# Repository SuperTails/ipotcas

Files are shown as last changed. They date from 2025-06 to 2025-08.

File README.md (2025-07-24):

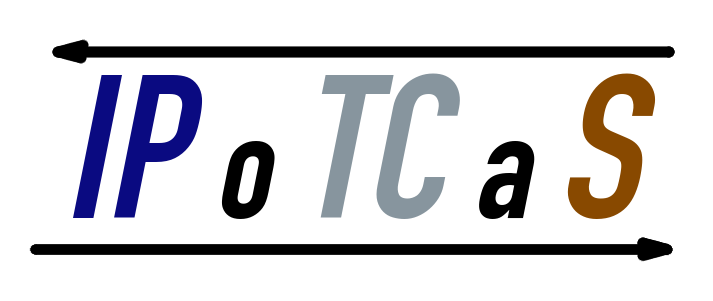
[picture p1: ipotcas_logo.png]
IPoTCaS logo


**IP over Tin Can and String** (IPoTCaS, pronounced "eye-poh-tee-kass"),
also known as EtherKnit or "what is this annoying buzzing noise",
is a revolutionary new way to connect to the internet over a fiber connection.

Using only two pieces of string and lots of annoying sounds,
IPoTCaS can create a **6.9 kbps** connection capable of browsing the web,
downloading files, and giving you a newfound distaste for web bloat.

# Physical Setup

The linear rails are sourced from two listings on Amazon,
but I'd highly recommend just using the first one because the wider rails are much worse
(though the CAD will require some modification):
- [Small rails](https://www.amazon.com/dp/B0D54LDBHN?ref=ppx_yo2ov_dt_b_fed_asin_title)
- [Large rails](https://www.amazon.com/dp/B088B6XN2J?ref=ppx_yo2ov_dt_b_fed_asin_title&th=1)

Any generic Kevlar kite string will probably work,
but I used specifically
[this amazon listing](https://www.amazon.com/dp/B088PT4KKG?ref=ppx_yo2ov_dt_b_fed_asin_title&th=1)
from `emma kites`.

The mount CAD is available on
[Onshape](https://cad.onshape.com/documents/322e68c2d75961563174bd8a/w/bb42fd02dcb60f17fdcb0973/e/e357883cf5ed7cb39072be44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).
I have not tested with materials other than PLA.
The model is designed to work with metric heat-set inserts to hold down the rails.

# Modulation

IPoTCaS uses 32-QAM and 12-carrier OFDM between 7 and 14 kHz.

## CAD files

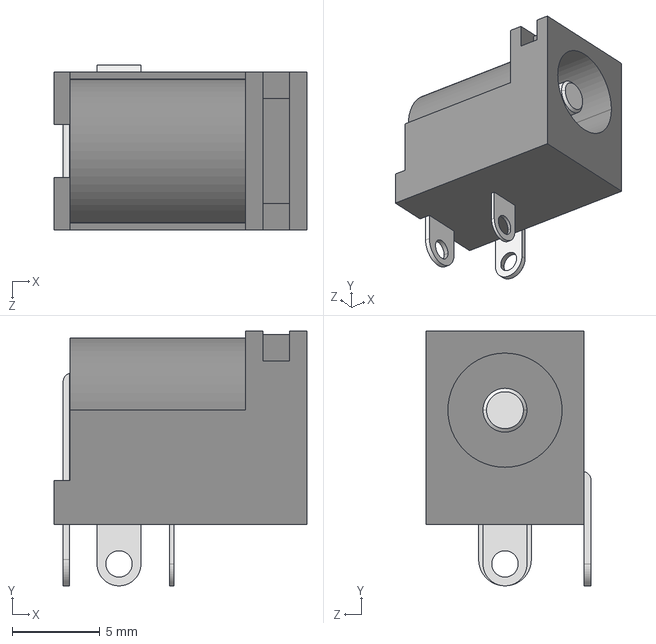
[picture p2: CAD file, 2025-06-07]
pcb/ipotcas/Custom/PJ-002B/PJ-002B.step
14.4 x 14.5 x 9.40 mm

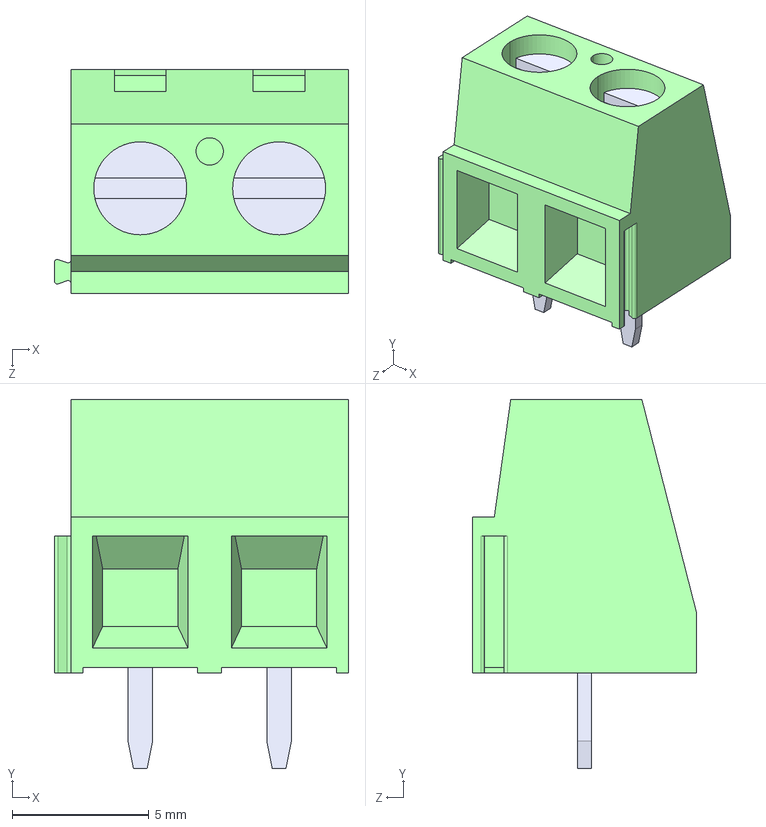
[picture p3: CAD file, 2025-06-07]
pcb/ipotcas/Custom/282837_2/282837-2.step
10.8 x 13.5 x 8.20 mm

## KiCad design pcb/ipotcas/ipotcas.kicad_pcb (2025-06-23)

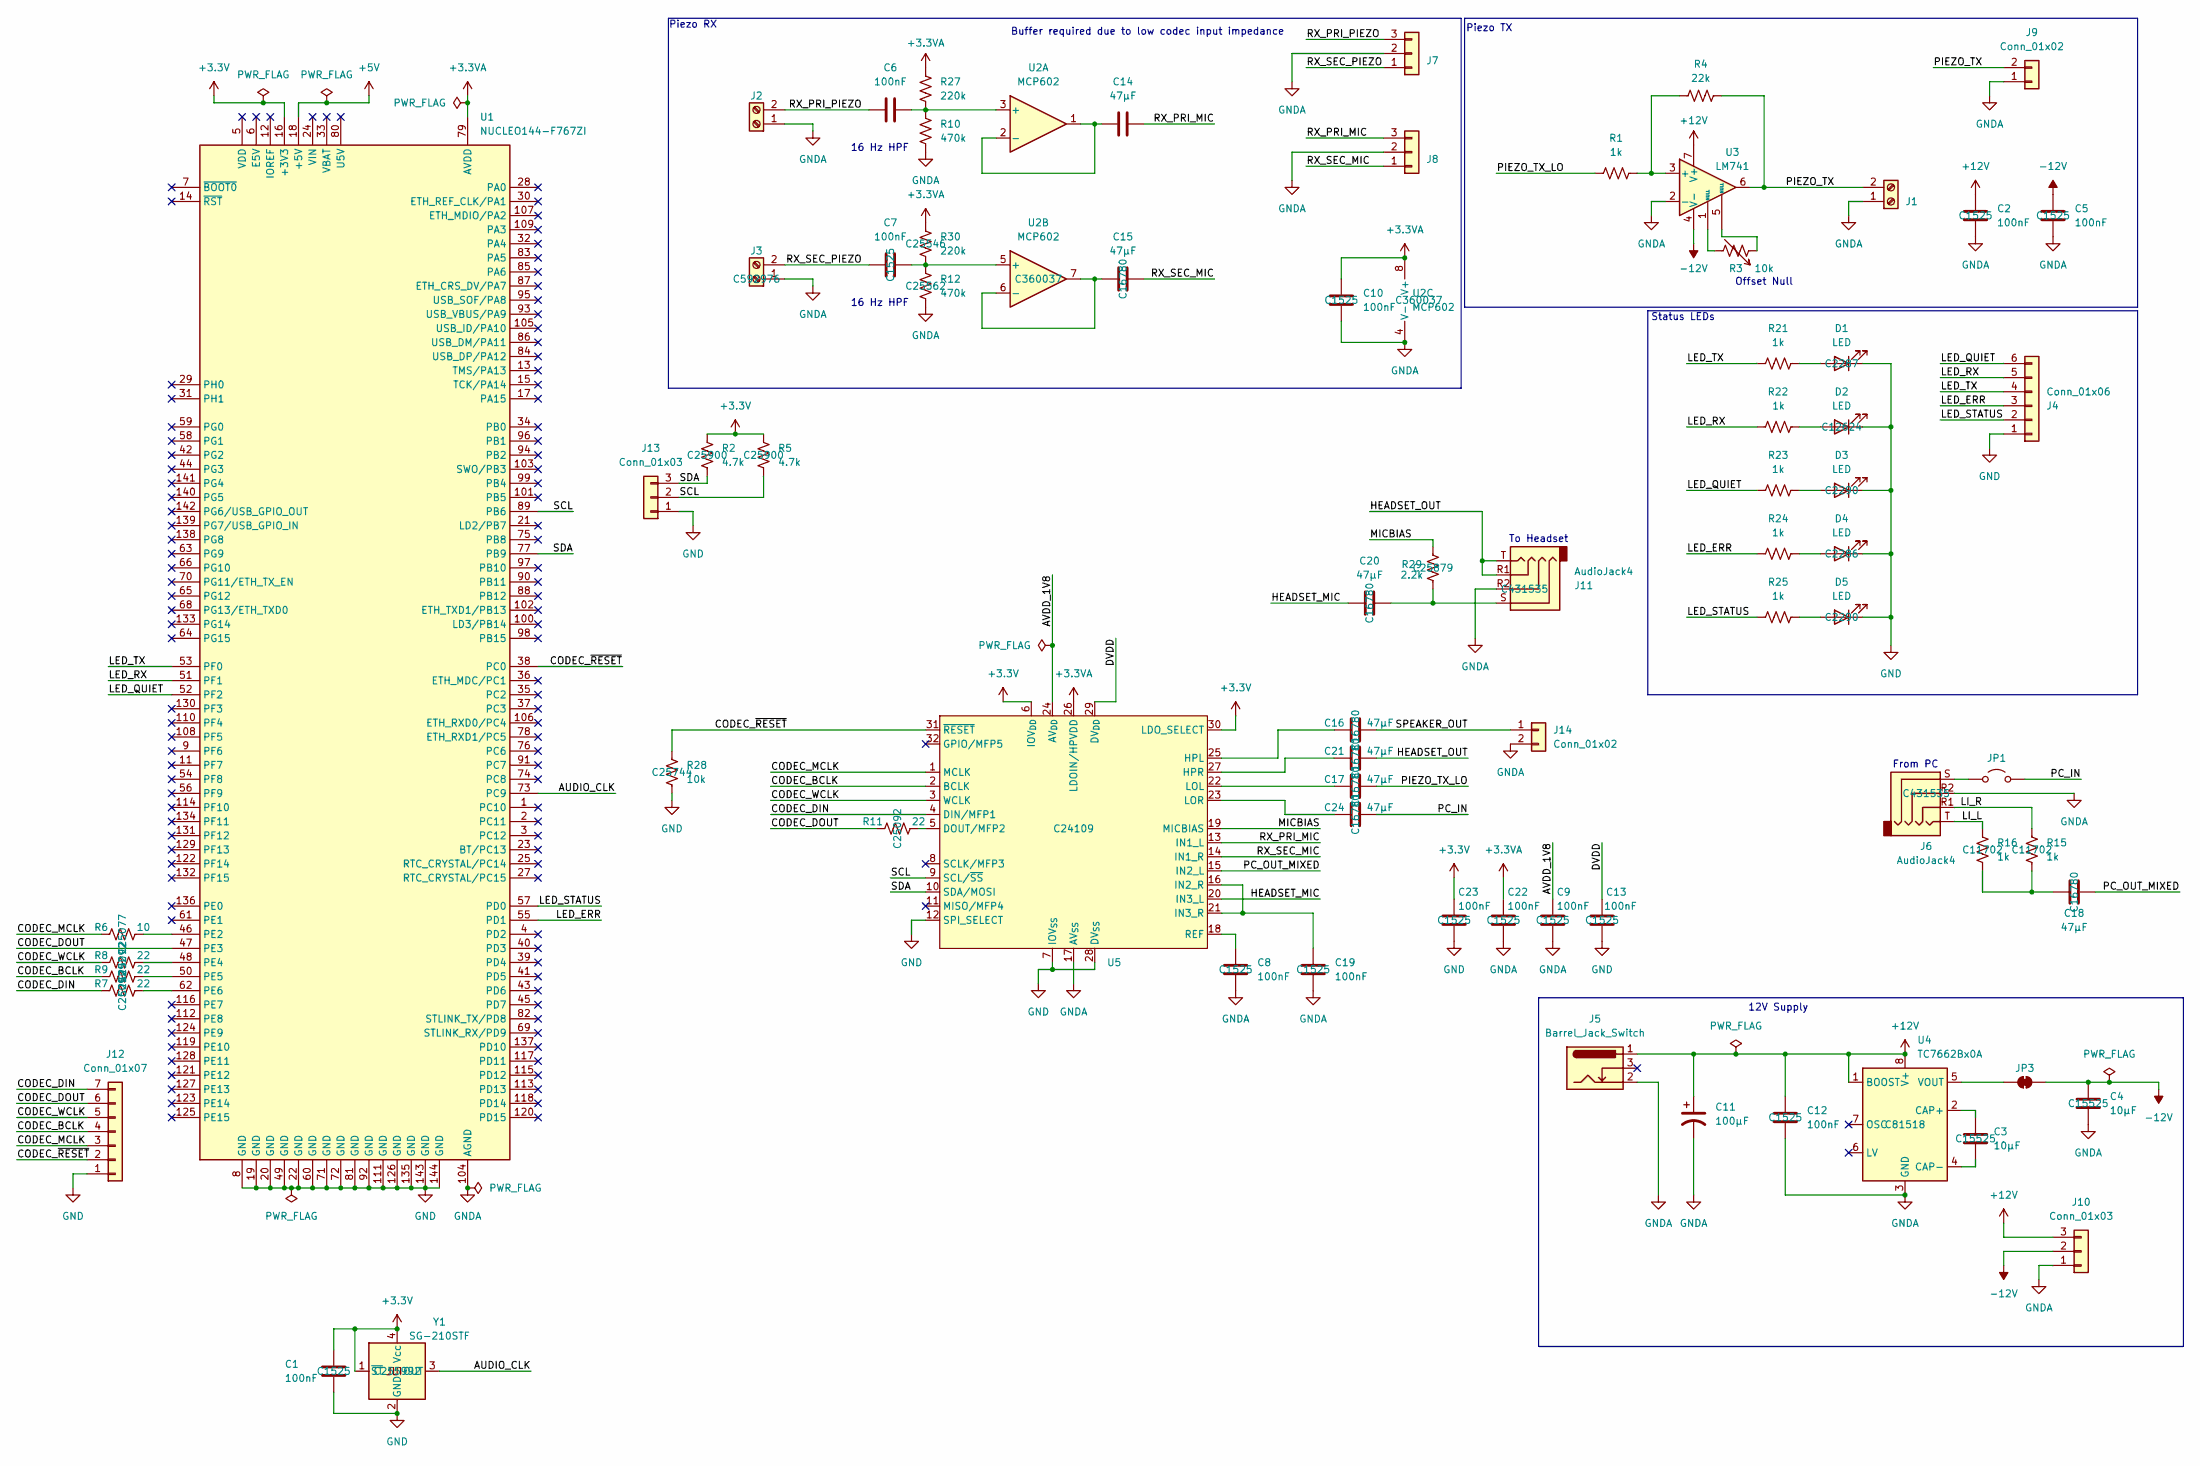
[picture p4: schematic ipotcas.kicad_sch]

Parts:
C1, C2, C5, C8, C9, C10, C12, C13, C19, C22, C23: 100nF; C_0402_1005Metric; JLC P/N C1525
C3, C4: 10µF; C_0402_1005Metric; JLC P/N C15525
C6, C7: 100nF; C_0402_1005Metric_Pad0.74x0.62mm_HandSolder; JLC P/N C1525
C11: 100µF; CP_Radial_D5.0mm_P2.50mm
C14, C15, C16, C17, C18, C20, C24: 47µF; C_0805_2012Metric; JLC P/N C16780
C21: 47µF; C_0603_1608Metric_Pad1.08x0.95mm_HandSolder; JLC P/N C16780
D1: LED; LED_0805_2012Metric_Pad1.15x1.40mm_HandSolder; JLC P/N C2287
D2: LED; LED_0805_2012Metric_Pad1.15x1.40mm_HandSolder; JLC P/N C12624
D3, D5: LED; LED_0805_2012Metric_Pad1.15x1.40mm_HandSolder; JLC P/N C2290
D4: LED; LED_0805_2012Metric_Pad1.15x1.40mm_HandSolder; JLC P/N C2286
J1, J2, J3: Screw_Terminal_01x02; TE_282837-2; JLC P/N C592976
J4: Conn_01x06; PinHeader_1x06_P2.54mm_Vertical
J5: Barrel_Jack_Switch; CUI_PJ-002B
J6, J11: AudioJack4; Jack_3.5mm_PJ320D_Horizontal; JLC P/N C431535
J7, J8, J10, J13: Conn_01x03; PinHeader_1x03_P2.54mm_Vertical
J9: Conn_01x02; PinHeader_1x02_P2.54mm_Vertical
J12: Conn_01x07; PinHeader_1x07_P2.54mm_Vertical
J14: Conn_01x02; PinSocket_1x02_P2.54mm_Vertical
JP1: Jumper_2_Open; PinHeader_1x02_P2.54mm_Vertical
JP3: SolderJumper_2_Bridged; SolderJumper-2_P1.3mm_Bridged_RoundedPad1.0x1.5mm
R1: 1k; R_0402_1005Metric_Pad0.72x0.64mm_HandSolder; JLC P/N C11702
R2, R5: 4.7k; R_0402_1005Metric; JLC P/N C25900
R3: 10k; Potentiometer_Bourns_3296W_Vertical; JLC P/N C118954
R4: 22k; R_0402_1005Metric_Pad0.72x0.64mm_HandSolder; JLC P/N C25768
R6: 10; R_0402_1005Metric; JLC P/N C25077
R7, R8, R9, R11: 22; R_0402_1005Metric; JLC P/N C25092
R10, R12: 470k; R_0402_1005Metric_Pad0.72x0.64mm_HandSolder; JLC P/N C25562
R15, R16: 1k; R_0402_1005Metric; JLC P/N C11702
R21, R22, R23, R24, R25: 1k; R_0805_2012Metric_Pad1.20x1.40mm_HandSolder
R27, R30: 220k; R_0402_1005Metric_Pad0.72x0.64mm_HandSolder; JLC P/N C25546
R28: 10k; R_0402_1005Metric; JLC P/N C25744
R29: 2.2k; R_0402_1005Metric; JLC P/N C25879
U1: NUCLEO144-F767ZI; ST_Morpho_Connector_144_STLink
U2: MCP602; SOIC-8_3.9x4.9mm_P1.27mm; JLC P/N C360037
U3: LM741; SOP-8_3.9x4.9mm_P1.27mm; JLC P/N C5145278
U4: TC7662Bx0A; SOIC-8_3.9x4.9mm_P1.27mm; JLC P/N C81518
U5: QFN-32-1EP_5x5mm_P0.5mm_EP3.45x3.45mm_ThermalVias; JLC P/N C24109
Y1: SG-210STF; Oscillator_SMD_SeikoEpson_SG210-4Pin_2.5x2.0mm; JLC P/N C255992

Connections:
+3.3V: C1.1, C23.1, R2.1, R5.1, U1.16 (+3V3), U5.6 (IOV_{DD}), U5.30 (LDO_SELECT), Y1.1 (~ST), Y1.4 (Vcc)
+3.3VA: C10.1, C22.1, R27.1, R30.1, U1.79 (AVDD), U2.8 (V+), U5.26 (LDOIN/HPVDD)
+5V: U1.18 (+5V)
+12V: C2.1, C11.1, C12.1, J5.1, J10.3, U3.7 (V+), U4.1 (BOOST), U4.8 (V+)
-12V: C4.1, C5.1, J10.2, JP3.2 (B), U3.4 (V-)
/AUDIO_CLK: U1.73 (PC9), Y1.3 (OUT)
/AVDD_1V8: C9.1, U5.24 (AV_{DD})
/CODEC_BCLK: J12.4, R9.1, U5.2 (BCLK)
/CODEC_DIN: J12.7, R7.1, U5.4 (DIN/MFP1)
/CODEC_DOUT: J12.6, R11.1, U1.47 (PE3)
/CODEC_MCLK: J12.3, R6.1, U5.1 (MCLK)
/CODEC_WCLK: J12.5, R8.1, U5.3 (WCLK)
/CODEC_~RESET: J12.2, R28.1, U1.38 (PC0), U5.31 (~RESET)
/DVDD: C13.1, U5.29 (DV_{DD})
/HEADSET_MIC: C20.1, U5.20 (IN3_L)
/HEADSET_OUT: C21.2, J11.R1, J11.T
/LED_ERR: J4.3, R24.1, U1.55 (PD1)
/LED_QUIET: J4.6, R23.1, U1.52 (PF2)
/LED_RX: J4.5, R22.1, U1.51 (PF1)
/LED_STATUS: J4.2, R25.1, U1.57 (PD0)
/LED_TX: J4.4, R21.1, U1.53 (PF0)
/LI_L: J6.T, R16.1
/LI_R: J6.R1, R15.1
/MICBIAS: R29.2, U5.19 (MICBIAS)
/PC_IN: C24.2, JP1.2 (B)
/PC_OUT_MIXED: C18.2, U5.15 (IN2_L)
/PIEZO_TX: J1.2, J9.2, R4.2, U3.6
/PIEZO_TX_LO: C17.2, R1.1
/RX_PRI_MIC: C14.2, J8.3, U5.13 (IN1_L)
/RX_PRI_PIEZO: C6.1, J2.2, J7.3
/RX_SEC_MIC: C15.2, J8.1, U5.14 (IN1_R)
/RX_SEC_PIEZO: C7.1, J3.2, J7.1
/SCL: J13.2, R5.2, U1.89 (PB6), U5.9 (SCL/~SS)
/SDA: J13.3, R2.2, U1.77 (PB9), U5.10 (SDA/MOSI)
/SPEAKER_OUT: C16.2, J14.1
GND: C1.2, C13.2, C23.2, D1.1 (K), D2.1 (K), D3.1 (K), D4.1 (K), D5.1 (K), J4.1, J12.1, J13.1, R28.2, U1.8 (GND), U1.19 (GND), U1.20 (GND), U1.22 (GND), U1.49 (GND), U1.60 (GND), U1.71 (GND), U1.72 (GND), U1.81 (GND), U1.92 (GND), U1.111 (GND), U1.126 (GND), U1.135 (GND), U1.143 (GND), U1.144 (GND), U5.7 (IOV_{SS}), U5.12 (SPI_SELECT), U5.28 (DV_{SS}), Y1.2 (GND)
GNDA: C2.2, C4.2, C5.2, C8.2, C9.2, C10.2, C11.2, C12.2, C19.2, C22.2, J1.1, J2.1, J3.1, J5.2, J6.R2, J7.2, J8.2, J9.1, J10.1, J11.R2, J14.2, R10.2, R12.2, U1.104 (AGND), U2.4 (V-), U3.2 (-), U4.3 (GND), U5.17 (AV_{SS})
unnamed: C18.1, R15.2, R16.2
unnamed: C20.2, J11.S, R29.1
unnamed: D1.2 (A), R21.2
unnamed: D2.2 (A), R22.2
unnamed: D3.2 (A), R23.2
unnamed: D4.2 (A), R24.2
unnamed: D5.2 (A), R25.2
unnamed: J6.S, JP1.1 (A)
unnamed: JP3.1 (A), U4.5 (VOUT)
unnamed: R3.1, U3.5 (NULL)
unnamed: R3.2, U3.1 (NULL)
unnamed: R6.2, U1.46 (PE2)
unnamed: R8.2, U1.48 (PE4)
unnamed: R9.2, U1.50 (PE5)
unnamed: R7.2, U1.62 (PE6)
unnamed: C6.2, R10.1, R27.2, U2.3 (+)
unnamed: C14.1, U2.1, U2.2 (-)
unnamed: C7.2, R12.1, R30.2, U2.5 (+)
unnamed: C15.1, U2.6 (-), U2.7
unnamed: R1.2, R4.1, U3.3 (+)
unnamed: C3.1, U4.2 (CAP+)
unnamed: C3.2, U4.4 (CAP-)
unnamed: R11.2, U5.5 (DOUT/MFP2)
unnamed: C16.1, U5.25 (HPL)
unnamed: C21.1, U5.27 (HPR)
unnamed: C19.1, U5.16 (IN2_R), U5.21 (IN3_R)
unnamed: C17.1, U5.22 (LOL)
unnamed: C24.1, U5.23 (LOR)
unnamed: C8.1, U5.18 (REF)

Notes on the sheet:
16 Hz HPF
To Headset
Piezo TX
Buffer required due to low codec input impedance
Piezo RX
12V Supply
Status LEDs
Offset Null
From PC

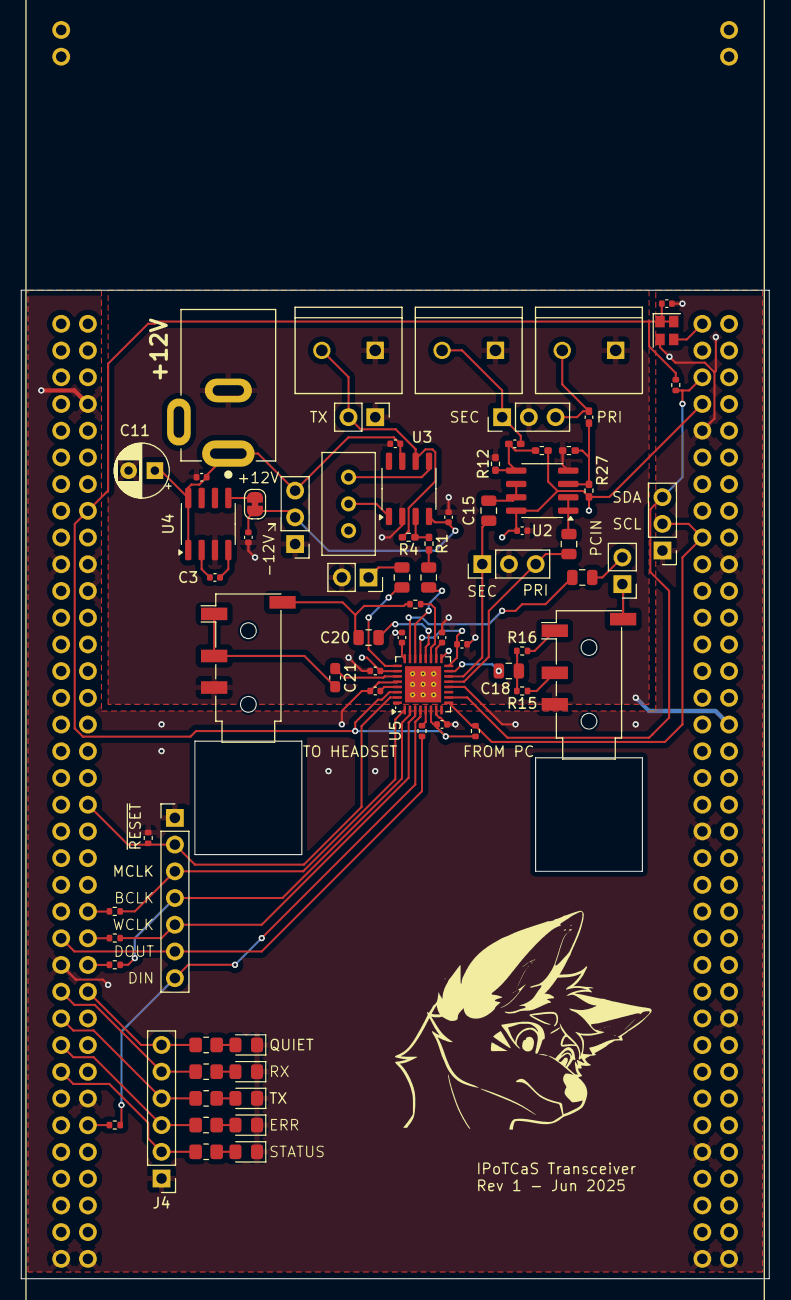
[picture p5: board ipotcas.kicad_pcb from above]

Board: 4 copper layers, 71.1 x 94.0 mm, 74 parts (0 on the bottom side), 65 nets.

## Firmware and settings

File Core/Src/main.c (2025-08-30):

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
/* Includes ------------------------------------------------------------------*/
#include "main.h"
#include "stm32f7xx_hal_uart.h"
#include "string.h"

/* USER CODE BEGIN Includes */
#include "tusb.h"
#include "transmit.h"
#include "receive.h"
#include "modulation.h"
#include "codec.h"
#include "ethernet.h"
#include <stdio.h>
/* USER CODE END Includes */

/* USER CODE BEGIN PD */

const char TEST_DATA[] =
    "Somebody once told me the world is gonna roll me / "
    "I ain't the sharpest tool in the shed / ";


#if 0
const char TEST_DATA[] =
    "Somebody once told me the world is gonna roll me / "
    "I ain't the sharpest tool in the shed / "
    "She was looking kind of dumb with her finger and her thumb / "
    "In the shape of an \"L\" on her forehead / "
    "Well, the years start comin' and they don't stop comin' / "
    "Fed to the rules and I hit the ground runnin' / "
    "Didn't make sense not to live for fun / "
    "Your brain gets smart but your head gets dumb / "
    "So much to do, so much to see / "
    "So what's wrong with taking the backstreets? / "
    "You'll never know if you don't go / "
    "You'll never shine if you don't glow / "
    "Hey now, you're an all star / "
    "Get your game on, go play / "
    "Hey now, you're a rock star / "
    "Get your show on, get paid / "
    "(And all that glitters is gold) / "
    "Only shootin' stars break the mold / "
    "It's a cool place, and they say it gets colder / "
    "You're bundled up now, wait 'til you get older / "
    "But the meteor men beg to differ / "
    "Judging by the hole in the satellite picture / "
    "The ice we skate is gettin' pretty thin / "
    "The waters gettin' warm so you might as well swim / "
    "My world's on fire, how 'bout yours? / "
    "That's the way I like it and I'll never get bored / "
    "Hey now, you're an all star / "
    "Get your game on, go play / "
    "Hey now, you're a rock star / "
    "Get your show on, get paid / "
    "(All that glitters is gold) / "
    "Only shootin' stars break the mold / "
    "Go for the moon / "
    "G-g-g-go for the moon / "
    "Go for the moon / "
    "Go-go-go for the moon / "
    "Hey now, you're an all star / "
    "Get your game on, go play / "
    "Hey now, you're a rock star / "
    "Get your show on, get paid / "
    "(All that glitters is gold)";
  #endif

/* USER CODE END PD */

#if defined ( __ICCARM__ ) /*!< IAR Compiler */
#pragma location=0x2007c000
ETH_DMADescTypeDef  DMARxDscrTab[ETH_RX_DESC_CNT]; /* Ethernet Rx DMA Descriptors */
#pragma location=0x2007c0a0
ETH_DMADescTypeDef  DMATxDscrTab[ETH_TX_DESC_CNT]; /* Ethernet Tx DMA Descriptors */

#elif defined ( __CC_ARM )  /* MDK ARM Compiler */

__attribute__((at(0x2007c000))) ETH_DMADescTypeDef  DMARxDscrTab[ETH_RX_DESC_CNT]; /* Ethernet Rx DMA Descriptors */
__attribute__((at(0x2007c0a0))) ETH_DMADescTypeDef  DMATxDscrTab[ETH_TX_DESC_CNT]; /* Ethernet Tx DMA Descriptors */

#elif defined ( __GNUC__ ) /* GNU Compiler */

ETH_DMADescTypeDef DMARxDscrTab[ETH_RX_DESC_CNT] __attribute__((section(".RxDecripSection"))); /* Ethernet Rx DMA Descriptors */
ETH_DMADescTypeDef DMATxDscrTab[ETH_TX_DESC_CNT] __attribute__((section(".TxDecripSection")));   /* Ethernet Tx DMA Descriptors */
#endif

ETH_TxPacketConfig TxConfig;

ADC_HandleTypeDef hadc1;
DMA_HandleTypeDef hdma_adc1;

DAC_HandleTypeDef hdac;
DMA_HandleTypeDef hdma_dac1;

ETH_HandleTypeDef heth;

I2C_HandleTypeDef hi2c1;

SAI_HandleTypeDef hsai_BlockA1;
SAI_HandleTypeDef hsai_BlockB1;
DMA_HandleTypeDef hdma_sai1_a;

TIM_HandleTypeDef htim2;
TIM_HandleTypeDef htim3;
TIM_HandleTypeDef htim4;

UART_HandleTypeDef huart2;
UART_HandleTypeDef huart3;
DMA_HandleTypeDef hdma_usart2_tx;
DMA_HandleTypeDef hdma_usart3_rx;

PCD_HandleTypeDef hpcd_USB_OTG_FS;

/* USER CODE BEGIN PV */

uint8_t raw_uart_buf[288];

/* USER CODE END PV */

void SystemClock_Config(void);
static void MX_GPIO_Init(void);
static void MX_DMA_Init(void);
static void MX_ETH_Init(void);
static void MX_USART3_UART_Init(void);
static void MX_ADC1_Init(void);
static void MX_DAC_Init(void);
static void MX_TIM2_Init(void);
static void MX_USB_OTG_FS_PCD_Init(void);
static void MX_TIM3_Init(void);
static void MX_USART2_UART_Init(void);
static void MX_TIM4_Init(void);
static void MX_I2C1_Init(void);
static void MX_SAI1_Init(void);
/* USER CODE BEGIN 0 */
int _write(int fd, const char *ptr, int len) {
  HAL_StatusTypeDef hstatus;
  if (fd == 1 || fd == 2) {
    hstatus = HAL_UART_Transmit(&huart3, (const uint8_t *)ptr, len, HAL_MAX_DELAY);
    if (hstatus == HAL_OK) {
      return len;
    } else {
      return -1;
    }
  }
  return -1;
}

int hamming_corrections = 0;

uint16_t adc_val;

/* USER CODE END 0 */

/**
  * @brief  The application entry point.
  * @retval int
  */
int main(void)
{

  /* Enable the CPU Cache */

  /* Enable I-Cache---------------------------------------------------------*/
  SCB_EnableICache();

  /* Enable D-Cache---------------------------------------------------------*/
  SCB_EnableDCache();

  /* MCU Configuration--------------------------------------------------------*/

  /* Reset of all peripherals, Initializes the Flash interface and the Systick. */
  HAL_Init();

  /* Configure the system clock */
  SystemClock_Config();

  /* Initialize all configured peripherals */
  MX_GPIO_Init();
  MX_DMA_Init();
  MX_ETH_Init();
  MX_USART3_UART_Init();
  MX_ADC1_Init();
  MX_DAC_Init();
  MX_TIM2_Init();
  MX_USB_OTG_FS_PCD_Init();
  MX_TIM3_Init();
  MX_USART2_UART_Init();
  MX_TIM4_Init();
  MX_I2C1_Init();
  MX_SAI1_Init();
  /* USER CODE BEGIN 2 */

  // FIXME: Can't configure this in stm32cubemx for some reason?
  // Refilling the tx buffer is a very long process but not very latency-sensitive
  // so it gets a lower priority to allow the ADC interrupt to preempt it
  HAL_NVIC_SetPriority(DMA1_Stream5_IRQn, 2, 0);
  HAL_NVIC_SetPriority(DMA2_Stream1_IRQn, 2, 0);
  /* USER CODE END 2 */

  /* Infinite loop */
  /* USER CODE BEGIN WHILE */
  /*if(HAL_ADCEx_Calibration_Start(&hadc1, ADC_CALIB_OFFSET, ADC_SINGLE_ENDED) != HAL_OK) {
    Error_Handler();
  }*/

  printf("Hello, world!\n");

  codec_init();

  if (HAL_ADC_Start(&hadc1) != HAL_OK) {
    Error_Handler();
  }

  if (HAL_TIM_PWM_Start(&htim2, TIM_CHANNEL_1) != HAL_OK) {
    Error_Handler();
  }

  if (HAL_TIM_Base_Start_IT(&htim3) != HAL_OK) {
    Error_Handler();
  }

  if (HAL_TIM_Base_Start(&htim4) != HAL_OK) {
    Error_Handler();
  }

  tusb_init();

  int tx_ok = transmit_init(&hdac);
  if (tx_ok != HAL_OK) {
    printf("transmit init failed %d\n", tx_ok);
    Error_Handler();
  }

  extern uint64_t micros(void);

  // here so that it can actually print things
  for (int i = 0; i < 2; ++i) {
    if (ethernet_init()) {
      printf("ETHERNET OK\n");
      break;
    }
    printf("ETHERNET FAILED\n");
  }

  printf("filt %lx\n", heth.Instance->MACFFR);
  printf("eth %lx\n", heth.Instance->DMASR);

  // turn off all filtering (!!)
  //heth.Instance->MACFFR |= (1 << 31);
  // turn on promiscuous mode (no MAC addr filter)
  heth.Instance->MACFFR |= ETH_MACFFR_PM;

  //printf("filt after %lx\n", heth.Instance->MACFFR);

  #if 0
  uint32_t last = -1;
  uint32_t last2 = -1;
  uint32_t last3 = -1;
  while (1) {
    uint32_t num_rx = heth.Instance->MMCRGUFCR;
    if (num_rx != last) {
      printf("Num received %lu\n", num_rx);
      last = num_rx;
    }
    uint32_t dbg = heth.Instance->MACDBGR;
    if (dbg != last2) {
      printf("DBG: %lu\n", dbg);
      last2 = dbg;
    }
    uint32_t t = micros() / 1000000;
    if (t != last3) {
      last3 = t;
      printf("hewo %ld\n", t);
      ethernet_send_packet();
    }
  }
  #endif

  int rx_ok = receive_init();
  if (rx_ok != HAL_OK) {
    printf("receive init failed %d\n", rx_ok);
    Error_Handler();
  }

#if TX_RAW_STREAM
  int uart_ok = HAL_UART_Receive_DMA(&huart3, raw_uart_buf, sizeof(raw_uart_buf));
  if (uart_ok != HAL_OK) {
    printf("UART rx start failed %d\n", uart_ok);
    Error_Handler();
  }
#endif

  int s = 0;
  int calls = 0;
  int st = micros() / 1000000;
  int total_bytes = 0;
  uint64_t count_start = 0;
  while (1)
  {
    /* USER CODE END WHILE */

    /* USER CODE BEGIN 3 */
    int s2 = micros() / 1000000;
    /*if (!ethernet_ok && s != s2) {
      s = s2;
      ethernet_ok = ethernet_init();
      // turn off all filtering (!!)
      heth.Instance->MACFFR |= (1 << 31);
      printf("hewo\n");
    }*/

#if TX_RAW_STREAM
    if (need_new_raw_samples()) {
      printf("S\n");
    }
#endif

    if (s != s2) {
      s = s2;
      if (s2 != st) { printf("hewo %d %d %d %d\n", calls / (s2 - st), heth.Instance->MMCRGUFCR, hamming_corrections, huart3.RxState); }
    }


#if TX_RAW_STREAM
    tud_task();


#if 0
    if (tud_cdc_available() >= 64) {
      tud_cdc_read(sample_buf+sample_buf_idx, 64);
      sample_buf_idx += 64;
      total_bytes += 64;
    }

    if (sample_buf_idx == 384) {
      submit_raw_stream((int16_t *)sample_buf);
      sample_buf_idx = 0;
    }
#else

#endif
#else
    tud_task();

    static bool prev_btn_state = false;
    bool btn_state = HAL_GPIO_ReadPin(USER_Btn_GPIO_Port, USER_Btn_Pin);
    if (btn_state && !prev_btn_state && transmit_ready(sizeof(TEST_DATA))) {
      transmit_send(NULL, TEST_DATA, sizeof(TEST_DATA));
    }

    transmit_task(&hdac);
#endif

    receive_task();
    //ethernet_task();

    ++calls;
  }
  /* USER CODE END 3 */
}

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
/* USER CODE BEGIN 4 */


void HAL_UART_RxCpltCallback(UART_HandleTypeDef* huart) {
  if (huart == &huart3) {
    HAL_GPIO_WritePin(GPIOD, GPIO_PIN_1, 1);

    submit_raw_stream(raw_uart_buf);

    HAL_GPIO_WritePin(GPIOD, GPIO_PIN_1, 0);
  }
}


/* USER CODE END 4 */
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


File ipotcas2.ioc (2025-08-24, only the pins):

Mcu.UserName=STM32F767ZITx
PA0/WKUP.Signal=ADCx_IN0
PA1.GPIO_Label=RMII_REF_CLK [LAN8742A-CZ-TR_REFCLK0]
PA1.Signal=ETH_REF_CLK
PA10.GPIO_Label=USB_ID
PA10.Signal=USB_OTG_FS_ID
PA11.Signal=USB_OTG_FS_DM
PA12.Signal=USB_OTG_FS_DP
PA13.GPIO_Label=TMS
PA13.Signal=SYS_JTMS-SWDIO
PA14.GPIO_Label=TCK
PA14.Signal=SYS_JTCK-SWCLK
PA2.GPIO_Label=RMII_MDIO [LAN8742A-CZ-TR_MDIO]
PA2.Signal=ETH_MDIO
PA3.Signal=USART2_RX
PA4.Signal=COMP_DAC1_group
PA5.Signal=COMP_DAC2_group
PA7.GPIO_Label=RMII_CRS_DV [LAN8742A-CZ-TR_CRS_DV]
PA7.Signal=ETH_CRS_DV
PA8.GPIO_Label=USB_SOF [TP1]
PA8.Signal=USB_OTG_FS_SOF
PA9.GPIO_Label=USB_VBUS
PA9.Signal=USB_OTG_FS_VBUS
PB13.GPIO_Label=RMII_TXD1 [LAN8742A-CZ-TR_TXD1]
PB13.Signal=ETH_TXD1
PB3.GPIO_Label=SWO
PB3.Signal=SYS_JTDO-SWO
PB6.Signal=I2C1_SCL
PB7.GPIO_Label=LD2 [Blue]
PB7.Signal=GPIO_Output
PB9.Signal=I2C1_SDA
PC0.Signal=GPIO_Output
PC1.GPIO_Label=RMII_MDC [LAN8742A-CZ-TR_MDC]
PC1.Signal=ETH_MDC
PC13.GPIO_Label=USER_Btn [B1]
PC13.Signal=GPXTI13
PC14/OSC32_IN.Signal=RCC_OSC32_IN
PC15/OSC32_OUT.Signal=RCC_OSC32_OUT
PC4.GPIO_Label=RMII_RXD0 [LAN8742A-CZ-TR_RXD0]
PC4.Signal=ETH_RXD0
PC5.GPIO_Label=RMII_RXD1 [LAN8742A-CZ-TR_RXD1]
PC5.Signal=ETH_RXD1
PC9.Signal=I2S_CKIN
PD0.GPIO_Label=LED_STATUS
PD0.Signal=GPIO_Output
PD1.GPIO_Label=LED_ERR
PD1.Signal=GPIO_Output
PD5.Signal=USART2_TX
PD8.GPIO_Label=STLK_RX [STM32F103CBT6_PA3]
PD8.Signal=USART3_TX
PD9.GPIO_Label=STLK_TX [STM32F103CBT6_PA2]
PD9.Signal=USART3_RX
PE2.Signal=SAI1_MCLK_A
PE3.Signal=SAI1_SD_B
PE4.Signal=SAI1_FS_A
PE5.Signal=SAI1_SCK_A
PE6.Signal=SAI1_SD_A
PF0.GPIO_Label=LED_TX
PF0.Signal=GPIO_Output
PF1.GPIO_Label=LED_RX
PF1.Signal=GPIO_Output
PF2.GPIO_Label=LED_QUIET
PF2.Signal=GPIO_Output
PG11.GPIO_Label=RMII_TX_EN [LAN8742A-CZ-TR_TXEN]
PG11.Signal=ETH_TX_EN
PG13.GPIO_Label=RMII_TXD0 [LAN8742A-CZ-TR_TXD0]
PG13.Signal=ETH_TXD0
PG6.GPIO_Label=USB_PowerSwitchOn [STMPS2151STR_EN]
PG6.Signal=GPIO_Output
PG7.GPIO_Label=USB_OverCurrent [STMPS2151STR_FAULT]
PG7.Signal=GPIO_Input
PH0/OSC_IN.GPIO_Label=MCO [STM32F103CBT6_PA8]
PH0/OSC_IN.Signal=RCC_OSC_IN
PH1/OSC_OUT.Signal=RCC_OSC_OUT

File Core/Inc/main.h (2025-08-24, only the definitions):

#define USB_MSG_HEADER_LO 0x55FF
#define USB_MSG_HEADER_HI 0x00AA
#define USB_MSG_RX_SAMPLES 0x0001
#define USB_MSG_RX_CONS_POINTS 0x0002
#define USB_MSG_TX_AUDIO_ACK 0x0003
#define USER_Btn_Pin GPIO_PIN_13
#define USER_Btn_GPIO_Port GPIOC
#define LED_TX_Pin GPIO_PIN_0
#define LED_TX_GPIO_Port GPIOF
#define LED_RX_Pin GPIO_PIN_1
#define LED_RX_GPIO_Port GPIOF
#define LED_QUIET_Pin GPIO_PIN_2
#define LED_QUIET_GPIO_Port GPIOF
#define MCO_Pin GPIO_PIN_0
#define MCO_GPIO_Port GPIOH
#define RMII_MDC_Pin GPIO_PIN_1
#define RMII_MDC_GPIO_Port GPIOC
#define RMII_REF_CLK_Pin GPIO_PIN_1
#define RMII_REF_CLK_GPIO_Port GPIOA
#define RMII_MDIO_Pin GPIO_PIN_2
#define RMII_MDIO_GPIO_Port GPIOA
#define RMII_CRS_DV_Pin GPIO_PIN_7
#define RMII_CRS_DV_GPIO_Port GPIOA
#define RMII_RXD0_Pin GPIO_PIN_4
#define RMII_RXD0_GPIO_Port GPIOC
#define RMII_RXD1_Pin GPIO_PIN_5
#define RMII_RXD1_GPIO_Port GPIOC
#define RMII_TXD1_Pin GPIO_PIN_13
#define RMII_TXD1_GPIO_Port GPIOB
#define STLK_RX_Pin GPIO_PIN_8
#define STLK_RX_GPIO_Port GPIOD
#define STLK_TX_Pin GPIO_PIN_9
#define STLK_TX_GPIO_Port GPIOD
#define USB_PowerSwitchOn_Pin GPIO_PIN_6
#define USB_PowerSwitchOn_GPIO_Port GPIOG
#define USB_OverCurrent_Pin GPIO_PIN_7
#define USB_OverCurrent_GPIO_Port GPIOG
#define USB_SOF_Pin GPIO_PIN_8
#define USB_SOF_GPIO_Port GPIOA
#define USB_VBUS_Pin GPIO_PIN_9
#define USB_VBUS_GPIO_Port GPIOA
#define USB_ID_Pin GPIO_PIN_10
#define USB_ID_GPIO_Port GPIOA
#define TMS_Pin GPIO_PIN_13
#define TMS_GPIO_Port GPIOA
#define TCK_Pin GPIO_PIN_14
#define TCK_GPIO_Port GPIOA
#define LED_STATUS_Pin GPIO_PIN_0
#define LED_STATUS_GPIO_Port GPIOD
#define LED_ERR_Pin GPIO_PIN_1
#define LED_ERR_GPIO_Port GPIOD
#define RMII_TX_EN_Pin GPIO_PIN_11
#define RMII_TX_EN_GPIO_Port GPIOG
#define RMII_TXD0_Pin GPIO_PIN_13
#define RMII_TXD0_GPIO_Port GPIOG
#define SWO_Pin GPIO_PIN_3
#define SWO_GPIO_Port GPIOB
#define LD2_Pin GPIO_PIN_7
#define LD2_GPIO_Port GPIOB

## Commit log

2025-05-03 ip over uart :)
2025-05-03 Increased UART speed
2025-05-04 Fix bugs and misc cleanup
    [ethernet.c, main.c, modulation.h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]
2025-05-06 Adjust sample time
2025-05-14 WIP raised cosine filtering
2025-05-14 Use DMA for transmission
2025-05-15 Add real time decoding and frequency switching
2025-05-29 Compensate for phase drift
    [main.c, receive.c, transmit.c]
2025-06-07 Add PCB schematic rev1
    [282837-2.step, PJ-002B.step, ipotcas.kicad_pcb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]
2025-06-07 Fix silkscreen labeling
    [ipotcas.kicad_pcb]
2025-06-07 Fix clearance violation
    [ipotcas.kicad_pcb]
2025-06-16 Enable SAI and I2C1
2025-06-23 Port RX to new PCB
    [ipotcas.kicad_pcb, ipotcas.kicad_sch]
2025-06-25 Working 12 carrier pcb tx/rx
2025-07-21 Add all star button and fix AGC
    [codec.c, lib.rs, main.c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]
2025-07-24 Add filtering, increase data rate, code cleanup, readme update
2025-07-30 Add switch to demo ASK transmission
2025-08-24 Add DMA for raw streaming
2025-08-30 Fix raw audio streaming maybe
    [codec.c, ethernet.c, main.c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]

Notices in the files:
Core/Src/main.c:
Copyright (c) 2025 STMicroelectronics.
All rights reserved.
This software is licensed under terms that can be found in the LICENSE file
